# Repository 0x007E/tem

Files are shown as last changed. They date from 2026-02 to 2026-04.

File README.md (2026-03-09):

  

# `TEM` - TWI EEPROM Module

The `TEM` is a board with an [AT24CM0X](#additional-information) `EEPROM` or any other `EEPROM` that fits the pin setting of the board. The board itself is driven with a voltage from `3V3`-`5V`. The `EEPROM` can be protected from being written with the onboard switch `SW1`.

> The address setup of the `EEPROMs` can be setup with Jumper `JP1`/`JP2`for the first `EEPROM` and Jumper `JP3`/`JP4` for the second `EEPROM`.

| Experience | Level |
|:---|:-----:|
| Soldering | ?% |
| Mechanical | ?% |

# Downloads

| Type | File | Description |
|:---:|:---:|:---|
| Schematic | [pdf](https://github.com/0x007E/tem/releases/latest/download/schematic.pdf) / [cadlab](https://cadlab.io/project/29791/main/files) | Schematic files |
| Board | [pdf](https://github.com/0x007E/tem/releases/latest/download/pcb.pdf) / [cadlab](https://cadlab.io/project/29791/main/files) | Board file |
| Drill | [pdf](https://github.com/0x007E/tem/releases/latest/download/drill.pdf) | Drill file |
| PCB | [zip](https://github.com/0x007E/tem/releases/latest/download/kicad.zip) / [tar](https://github.com/0x007E/tem/releases/latest/download/kicad.tar.gz) |  	KiCAD/Gerber/BoM/Drill files |
| Mechanical | [zip](https://github.com/0x007E/diu/releases/latest/download/freecad.zip) / [tar](https://github.com/0x007E/diu/releases/latest/download/freecad.tar.gz) | FreeCAD/Housing and PCB (STEP) files |

# Hardware

The pcb is created with `KiCAD`, the housing with `FreeCAD`. All files are built with `github actions` so that they are ready for a production environment.

## PCB

The circuit board is populated on both sides (Top, Bottom). The best way for soldering the `SMD` components is within a vapor phase soldering system and for the `THT` components with a standard soldering system.

### Top Layer

Top Layer

### Bottom Layer

Bottom Layer

## Mechanical

The housing has a tolerance of `0.2mm` on each side of the case. So the pcb should fit perfectly in the housing. The tolerance can be modified with `FreeCAD` in the `Parameter` Spreadsheet.

### Assembled

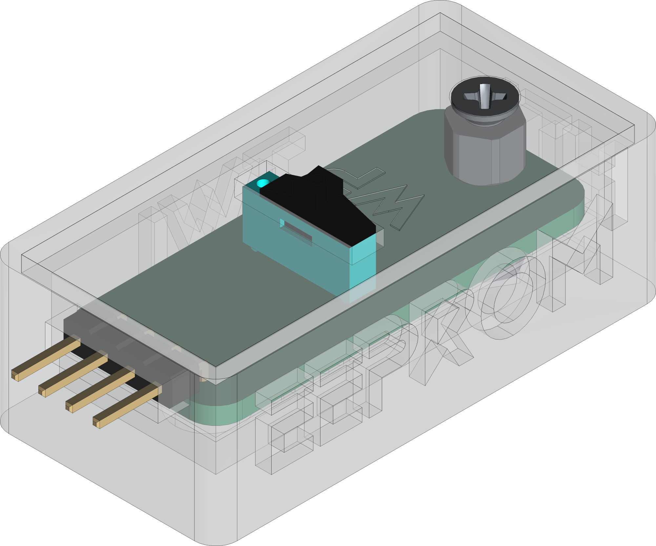
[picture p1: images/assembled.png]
Assembled


### Exploded

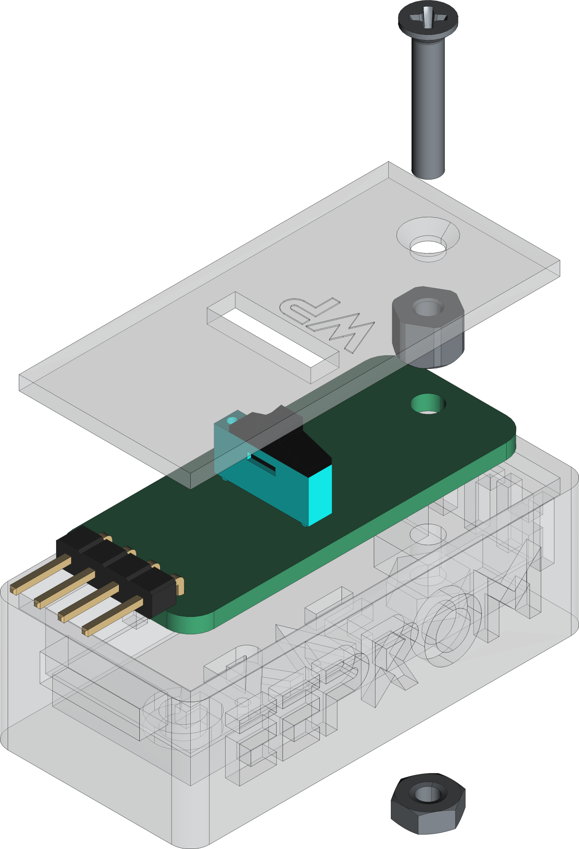
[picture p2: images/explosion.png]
Exploded


# Additional Information

| Type | Link | Description |
|:---:|:---:|:---|
| AT24CM02 | [pdf](https://ww1.microchip.com/downloads/en/DeviceDoc/AT24CM02-I2C-Compatible-Two-Wire-Serial-EEPROM-2-Mbit-262,144x8-20006197C.pdf) | 2-MBit serial EEPROM dataseheet |
| AT24CM01 | [pdf](https://ww1.microchip.com/downloads/en/DeviceDoc/AT24CM01-I2C-Compatible-Two-Wire-Serial-EEPROM-Data-Sheet-20006170A.pdf) | 1-MBit serial EEPROM datasheet |

---

R. GAECHTER

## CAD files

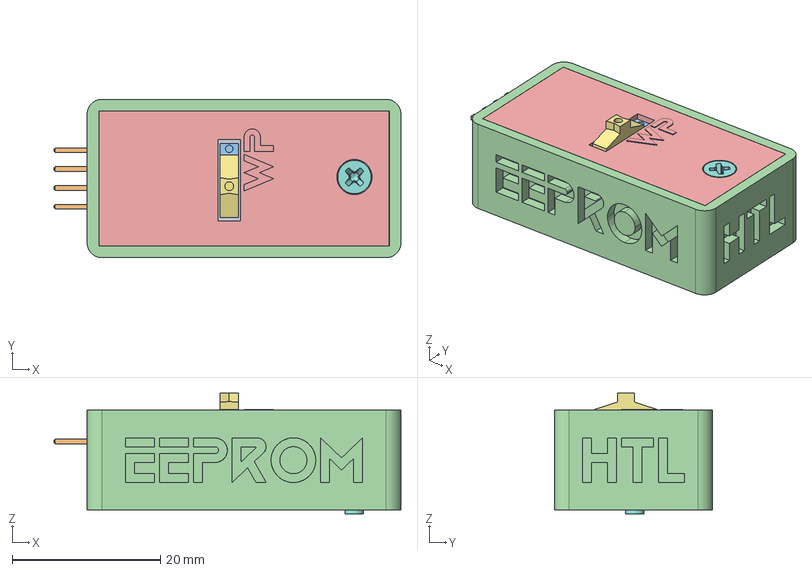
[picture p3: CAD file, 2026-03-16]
mechanical/housing.FCStd
46.8 x 21.4 x 16.3 mm
Pcb_e95e
J1_PinHeader_1x04_P254mm_Horizontal_67e2fbd67df2
CUI_DEVICES_MSS-102545-28A-D
CUI_DEVICES_MSS-102545-28A-D001
CUI_DEVICES_MSS-102545-28A-D002
CUI_DEVICES_MSS-102545-28A-D003
CUI_DEVICES_MSS-102545-28A-D004
U2_SOIC-8_3.9x4.9mm_P1.27mm_3e68edb716d5
U1_SOIC-8_3.9x4.9mm_P1.27mm_eeae3f03861c
R4_R_1206_3216Metric_2153681e1708
R1_R_1206_3216Metric_73354968f081
C2_C_1206_3216Metric_2df2ea831409
C3_C_1206_3216Metric_41c8615fcf1e
R3_R_1206_3216Metric_88814e0e38e8
C1_CP_EIA_6032_28_Kemet_C_caf7d15d7ffa
R6_R_1206_3216Metric_9fdea1ffc88e
R7_R_1206_3216Metric_ce710395c30e
R2_R_1206_3216Metric_ea23d613c7ea
R5_R_1206_3216Metric_8fba5ca2b483
M2.5-Nut
M2.5x4x5-Spacer
M2.5x14-Screw

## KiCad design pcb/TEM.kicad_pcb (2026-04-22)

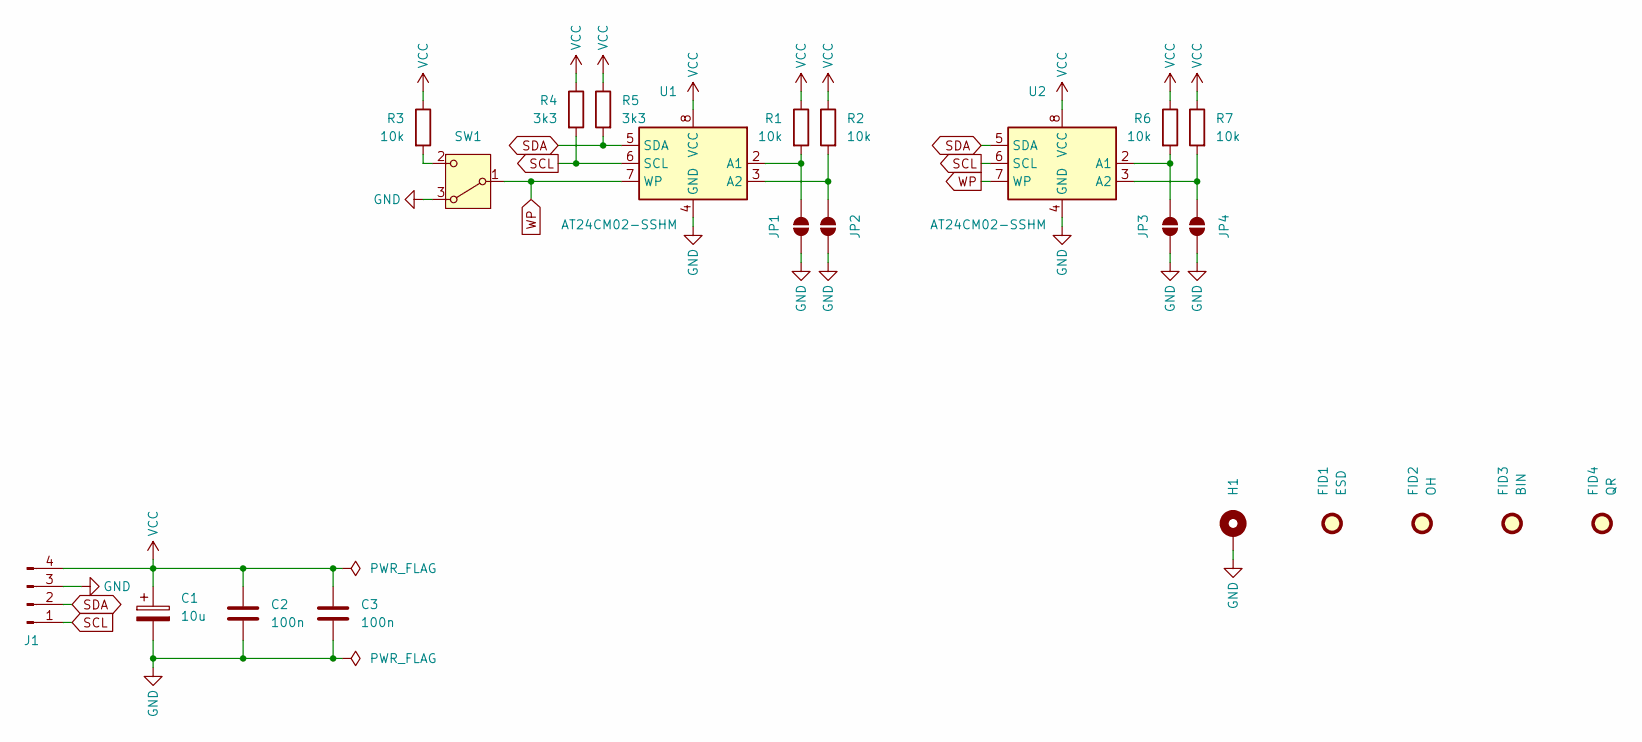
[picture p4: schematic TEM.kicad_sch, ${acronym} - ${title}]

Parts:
C1: 10u; CP_EIA-6032-28_Kemet-C
C2, C3: 100n; C_1206_3216Metric
FID1: ESD; ESD-Logo_6.6x6mm_SilkScreen
FID2: OH; OSHW-Logo_5.7x6mm_SilkScreen
FID3: BIN; WEEE-Logo_4.2x6mm_SilkScreen
FID4: QR; QR_0x007e_very_small
H1: MountingHole_Pad; MountingHole_2.7mm_M2.5_DIN965_Pad
J1: Conn_01x04_Pin; PinHeader_1x04_P2.54mm_Horizontal
JP1, JP2, JP3, JP4: SolderJumper_2_Open; SolderJumper-2_P1.3mm_Open_RoundedPad1.0x1.5mm
R1, R2, R3, R6, R7: 10k; R_1206_3216Metric
R4, R5: 3k3; R_1206_3216Metric
SW1: SW_Wuerth_450301014042; SW_Slide-03_Wuerth-WS-SLTV_10x2.5x6.4_P2.54mm
U1, U2: AT24CM02-SSHM; SOIC-8_3.9x4.9mm_P1.27mm

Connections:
GND: C1.2, C2.2, C3.2, H1.1, J1.3, JP1.1 (A), JP2.1 (A), JP3.1 (A), JP4.1 (A), SW1.3 (A), U1.4 (GND), U2.4 (GND)
unnamed: JP1.2 (B), R1.2, U1.2 (A1)
unnamed: JP2.2 (B), R2.2, U1.3 (A2)
unnamed: JP3.2 (B), R6.2, U2.2 (A1)
unnamed: JP4.2 (B), R7.2, U2.3 (A2)
unnamed: R3.2, SW1.2 (C)
SCL: J1.1, R4.2, U1.6 (SCL), U2.6 (SCL)
SDA: J1.2, R5.2, U1.5 (SDA), U2.5 (SDA)
VCC: C1.1, C2.1, C3.1, J1.4, R1.1, R2.1, R3.1, R4.1, R5.1, R6.1, R7.1, U1.8 (VCC), U2.8 (VCC)
WP: SW1.1 (B), U1.7 (WP), U2.7 (WP)

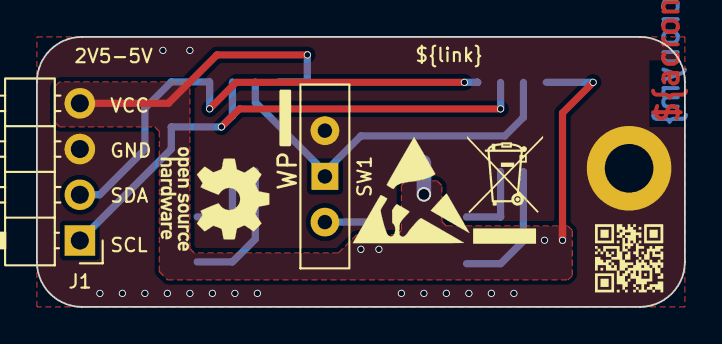
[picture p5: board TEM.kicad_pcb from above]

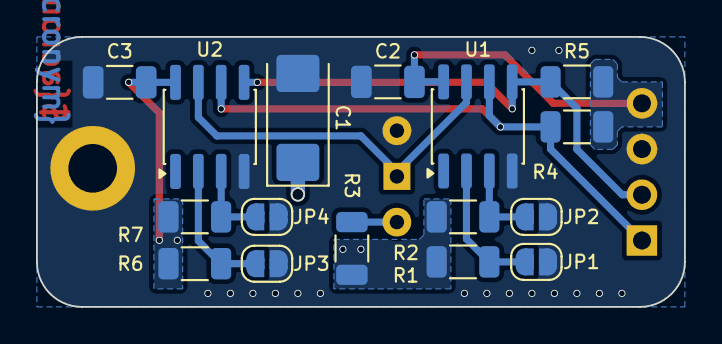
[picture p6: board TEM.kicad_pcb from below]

Board: 2 copper layers, 36.0 x 15.0 mm, 23 parts (16 on the bottom side), 10 nets.

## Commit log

2025-12-10 Add pcb layout
    [TEM.kicad_pcb, TEM.kicad_sch]
2025-12-10 Add mechanical parts
    [housing.FCStd]
2025-12-10 Swapped SCL/SDA
    [TEM.kicad_pcb, TEM.kicad_sch]
2025-12-10 Adapt vendors on partlist
    [TEM.kicad_pcb, TEM.kicad_sch]
2026-01-08 Add vendor id to partlist
    [TEM.kicad_pcb, TEM.kicad_sch]
2026-02-05 Add assembly explosion
    [housing.FCStd]
2026-02-06 Switched system language
    [TEM.kicad_pcb]
2026-03-09 Update footprints
    [TEM.kicad_pcb]
2026-03-16 Replace WP on silkscreen
    [TEM.kicad_pcb]
2026-03-16 Replace WP on acrylglass
    [housing.FCStd]
2026-04-08 Remove exclude from bom
    [TEM.kicad_pcb, TEM.kicad_sch]
2026-04-08 Add missing vendor(id)
    [TEM.kicad_pcb, TEM.kicad_sch]
2026-04-22 Adapt vendor(id)
    [TEM.kicad_pcb, TEM.kicad_sch]

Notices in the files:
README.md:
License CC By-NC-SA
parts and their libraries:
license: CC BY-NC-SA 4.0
